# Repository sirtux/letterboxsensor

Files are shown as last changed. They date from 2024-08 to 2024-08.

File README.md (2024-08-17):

# LoRaWAN EU868Mhz Letterbox Sensor

sensing letters in your letterbox via two infrared proximity sensors (HSDL9100),
sending out status via lora / lorawan, using RAK3172 (based on STM32WLE5CC) CPU/RF, powered by a CR2032 battery.

This project is a remake of https://github.com/hierle/letterbox-sensor-v2/, many thanks to the original author!

This design is built in a way, that it can be assembled by a factory house like JLCPCB and you do not need
to fiddle around with soldering small components - especially the HSDL9100 are very fiddly.

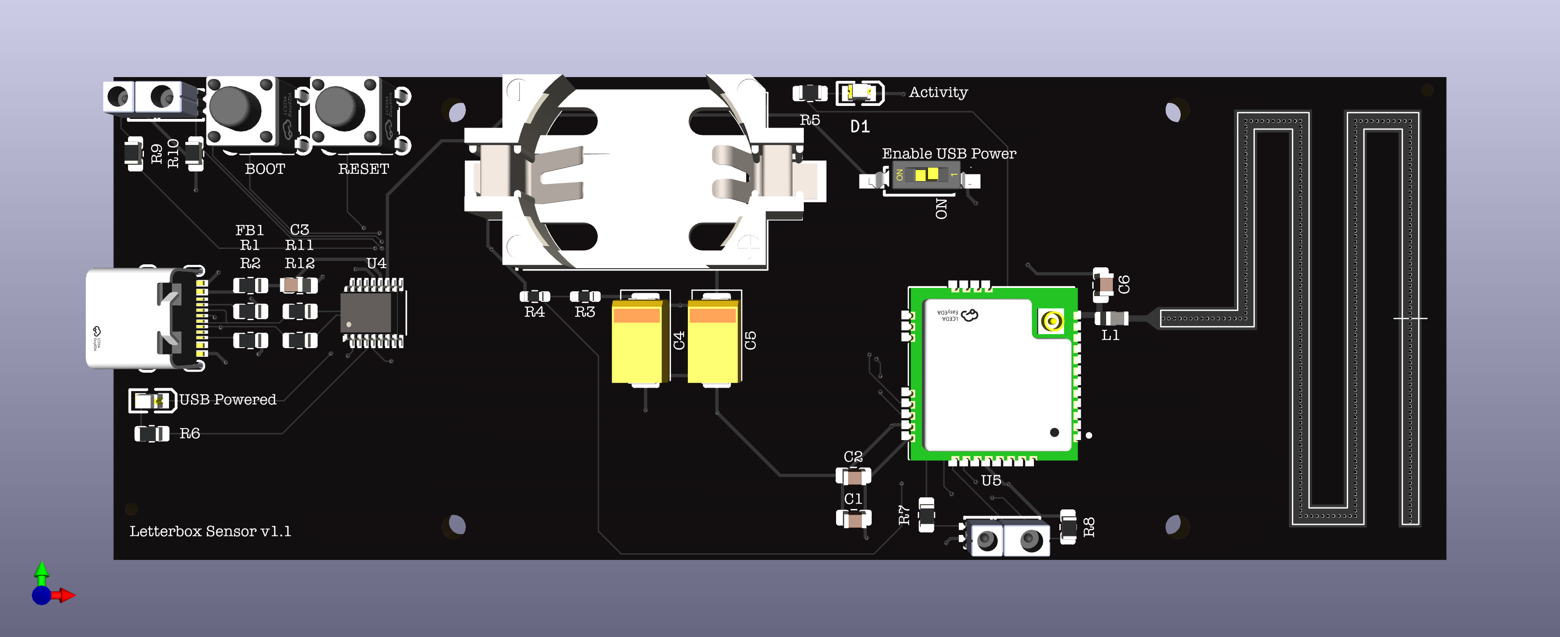
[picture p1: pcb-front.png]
LoRaWAN Letterbox Sensor PCB


Contents:

- ./letterboxsensor/		kicad design files
- ./jlclib/			library files for non standard components
- ./ttn/			Tools to setup TheThingsNetwork
- ./arduino/			Source Code for the sensor
- ./gerber/			Required files for PCB manufacturing
- ./jlcassembly/		Files for JLC Assembly Service

Features:
- using RAKWireless RAK3172 based on STM32WLE5CC
- deep sleep at (measured) 5uA including battery voltage divider and tantalium caps
- two proximity sensors HSDL9100
- USB-C interface for flashing and serial monitor, via FT230XS-R USB-UART
- onboard 868MHz PCB antenna after TI document http://www.ti.com/lit/an/swra227e/swra227e.pdf
- lorawan activation either ABP or OTAA
- battery voltage measurment thru voltage divider (2x 10MOhm)

RAK3172 documentation:

https://docs.rakwireless.com/Product-Categories/WisDuo/RAK3172-Module/Overview/

How to compile:

Follow the instructions on<br>
https://docs.rakwireless.com/Product-Categories/WisDuo/RAK3172-Module/Quickstart/<br>
in short:<br>
- install ArduinoIDE from arduino.cc
- add the following URL to the boards manager URLs section in preferences:
https://raw.githubusercontent.com/RAKWireless/RAKwireless-Arduino-BSP-Index/main/package_rakwireless.com_rui_index.json
- install the "RAKwireless RUI STM32 Boards" from the Boards Manager
- select "WisDuo RAK3172 Evaluation Board" board
- on Mac you might need to install pyserial: sudo pip3 install pyserial
- on Linux you might need to install python3-pyserial
- connect the board, make sure it's powered on (DIP switch)
- select the corresponding serial port
- open the sketch folder
- adjust config.h and lorawan.h
- compile and flash

For configuration adjust config.h and lorawan.h

config.h:
- PERIOD: the time intervall you want the sensor to send it's data, in minutes, default is 30 minutes
- THRESHOLD: the threshold for the sensor readings (empty/full), can later be "overwritten" in e.g. HTML integration
- USE_OTAA: if true, OTAA will be used instead of ABP, so we do not have to worry about frame counters after reset / battery change
- DATARATE and TXPOWER: adjust to your needs, your packets should be reliably received, w/o wasting to much power
- see also the comments for each entry in config.h

lorawan.h:
- set your lorawan keys for either ABP or OTAA
- OTAA_APPEUI or JOINEUI is only needed to select a specific JOIN server, in private networks can be set to any value

Additional notes:
- you will need a *DATA* USB-C cable, a charging only cable will not work, as it's missing the data pins ;-)
- the DIP switch allows to power the device directly from USB, but when using the battery in production environment (letterbox), it should be switched off, not to waist power on the FT230 USB-UART chip

Letterbox sensor v2 lorawan payload package byte structure:

|byte| 0 |  1 2 | 3 4 | 5 6 | 7 |
|----|---|---|---|---|---|
| |0x00=empty|battery |sensor1|sensor2|threshold|
| |0xFF=full |voltage |raw |raw | |

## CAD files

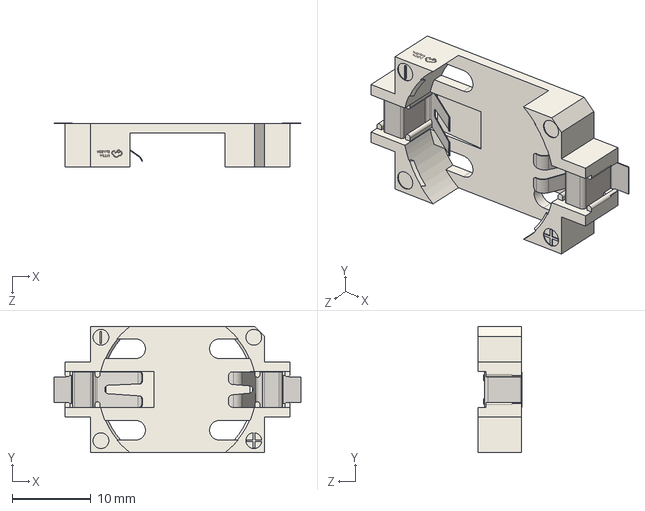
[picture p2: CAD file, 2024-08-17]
jlclib/footprints/models/BAT-TH_CR2032-BS-6-1.step
31.3 x 16.0 x 5.60 mm

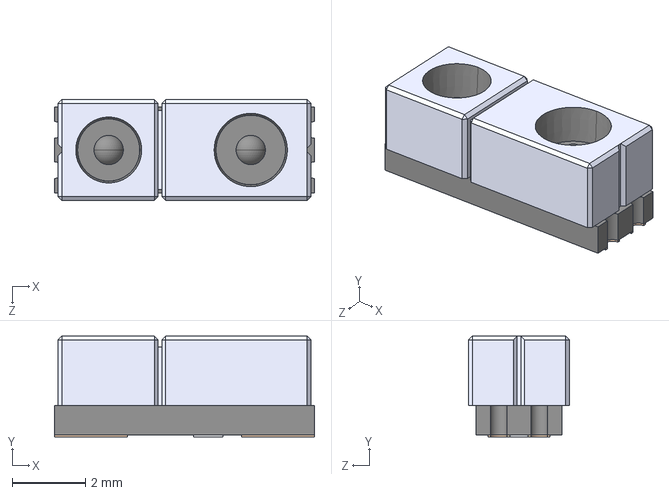
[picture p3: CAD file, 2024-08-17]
jlclib/footprints/models/hsdl9100.step
7.10 x 2.75 x 2.75 mm

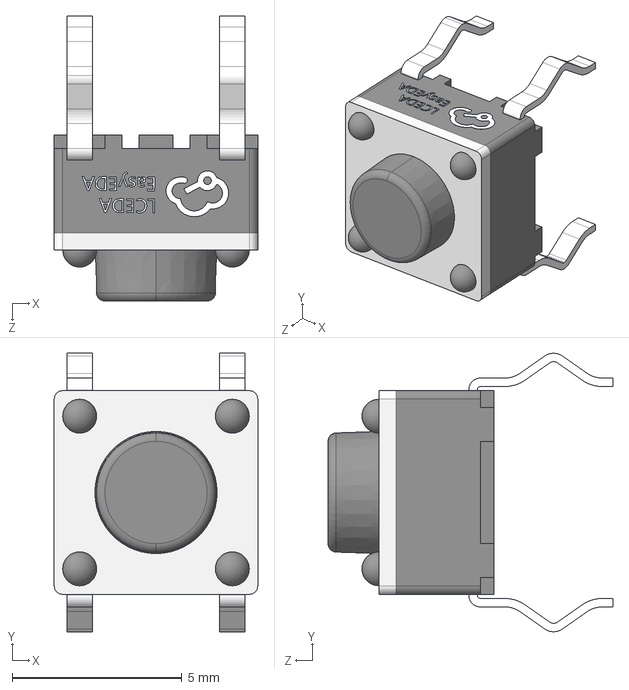
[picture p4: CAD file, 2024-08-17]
jlclib/footprints/models/SW-TH_4P-L6.0-W6.0-P4.50-LS6.5.step
6.00 x 8.21 x 8.40 mm

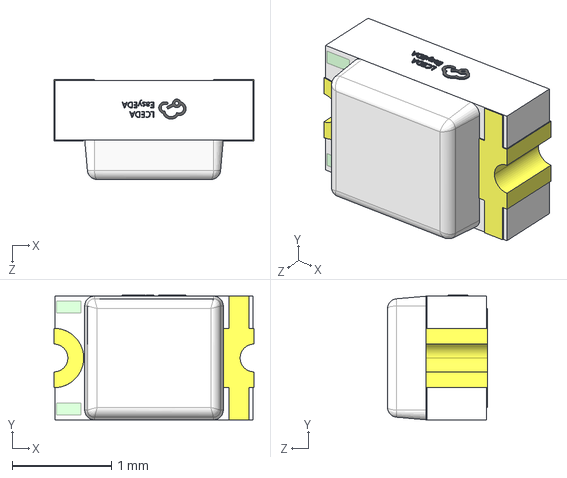
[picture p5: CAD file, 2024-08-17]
jlclib/footprints/models/LED0805-R-RD.step
2.02 x 1.26 x 1.01 mm

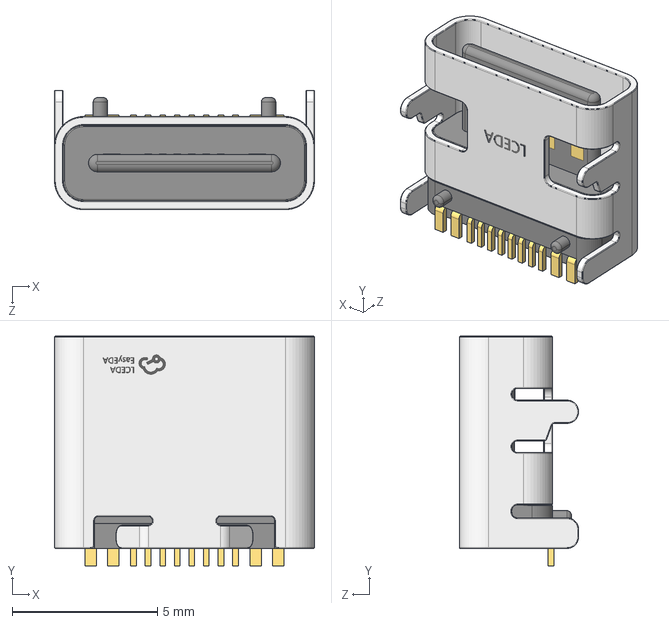
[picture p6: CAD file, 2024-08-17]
jlclib/footprints/models/USB-C-SMD_TYPE-C-USB-17.step
8.94 x 7.90 x 4.10 mm

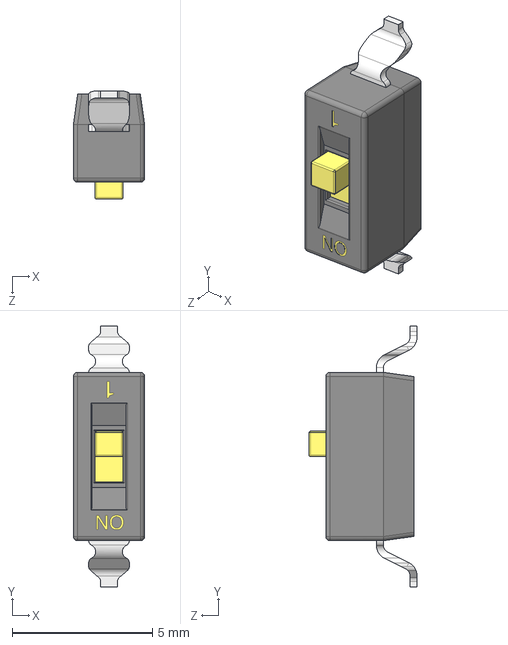
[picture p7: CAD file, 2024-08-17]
jlclib/footprints/models/SW-SMD_DSIC01LSGET.step
2.54 x 9.30 x 3.85 mm

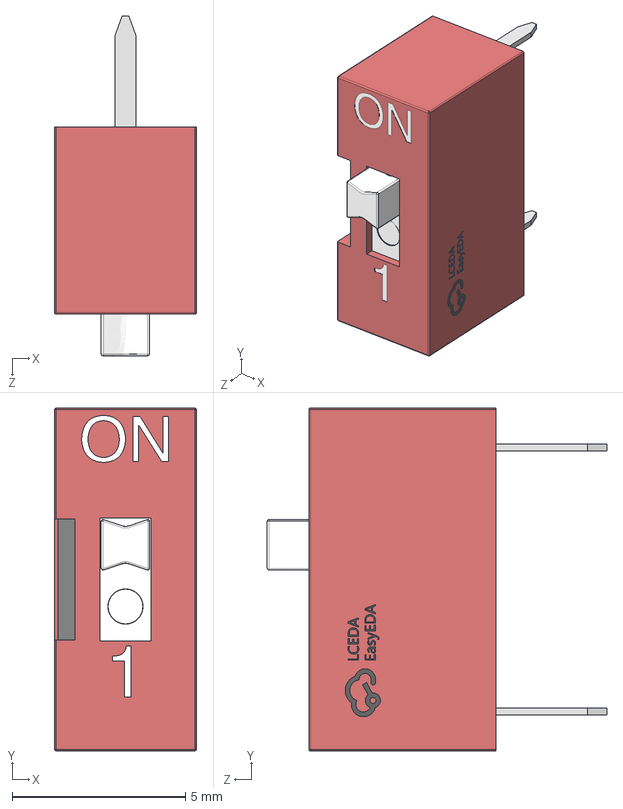
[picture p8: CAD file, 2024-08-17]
jlclib/footprints/models/SW-TH_DSWB01LHGET.step
4.10 x 9.90 x 9.80 mm

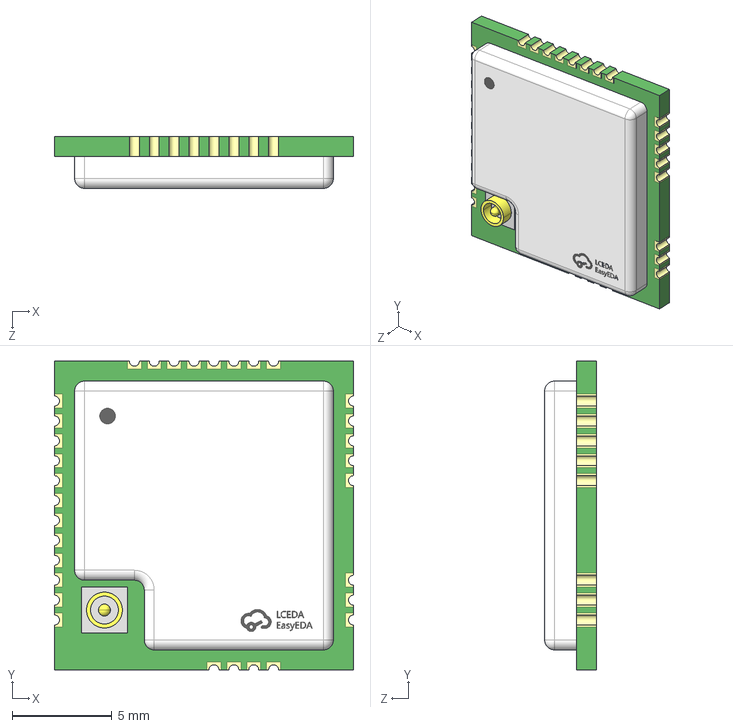
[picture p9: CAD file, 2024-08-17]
jlclib/footprints/models/WIRELM-SMD_32P-L15.5-W15.0-P1.00.step
15.0 x 15.5 x 2.62 mm

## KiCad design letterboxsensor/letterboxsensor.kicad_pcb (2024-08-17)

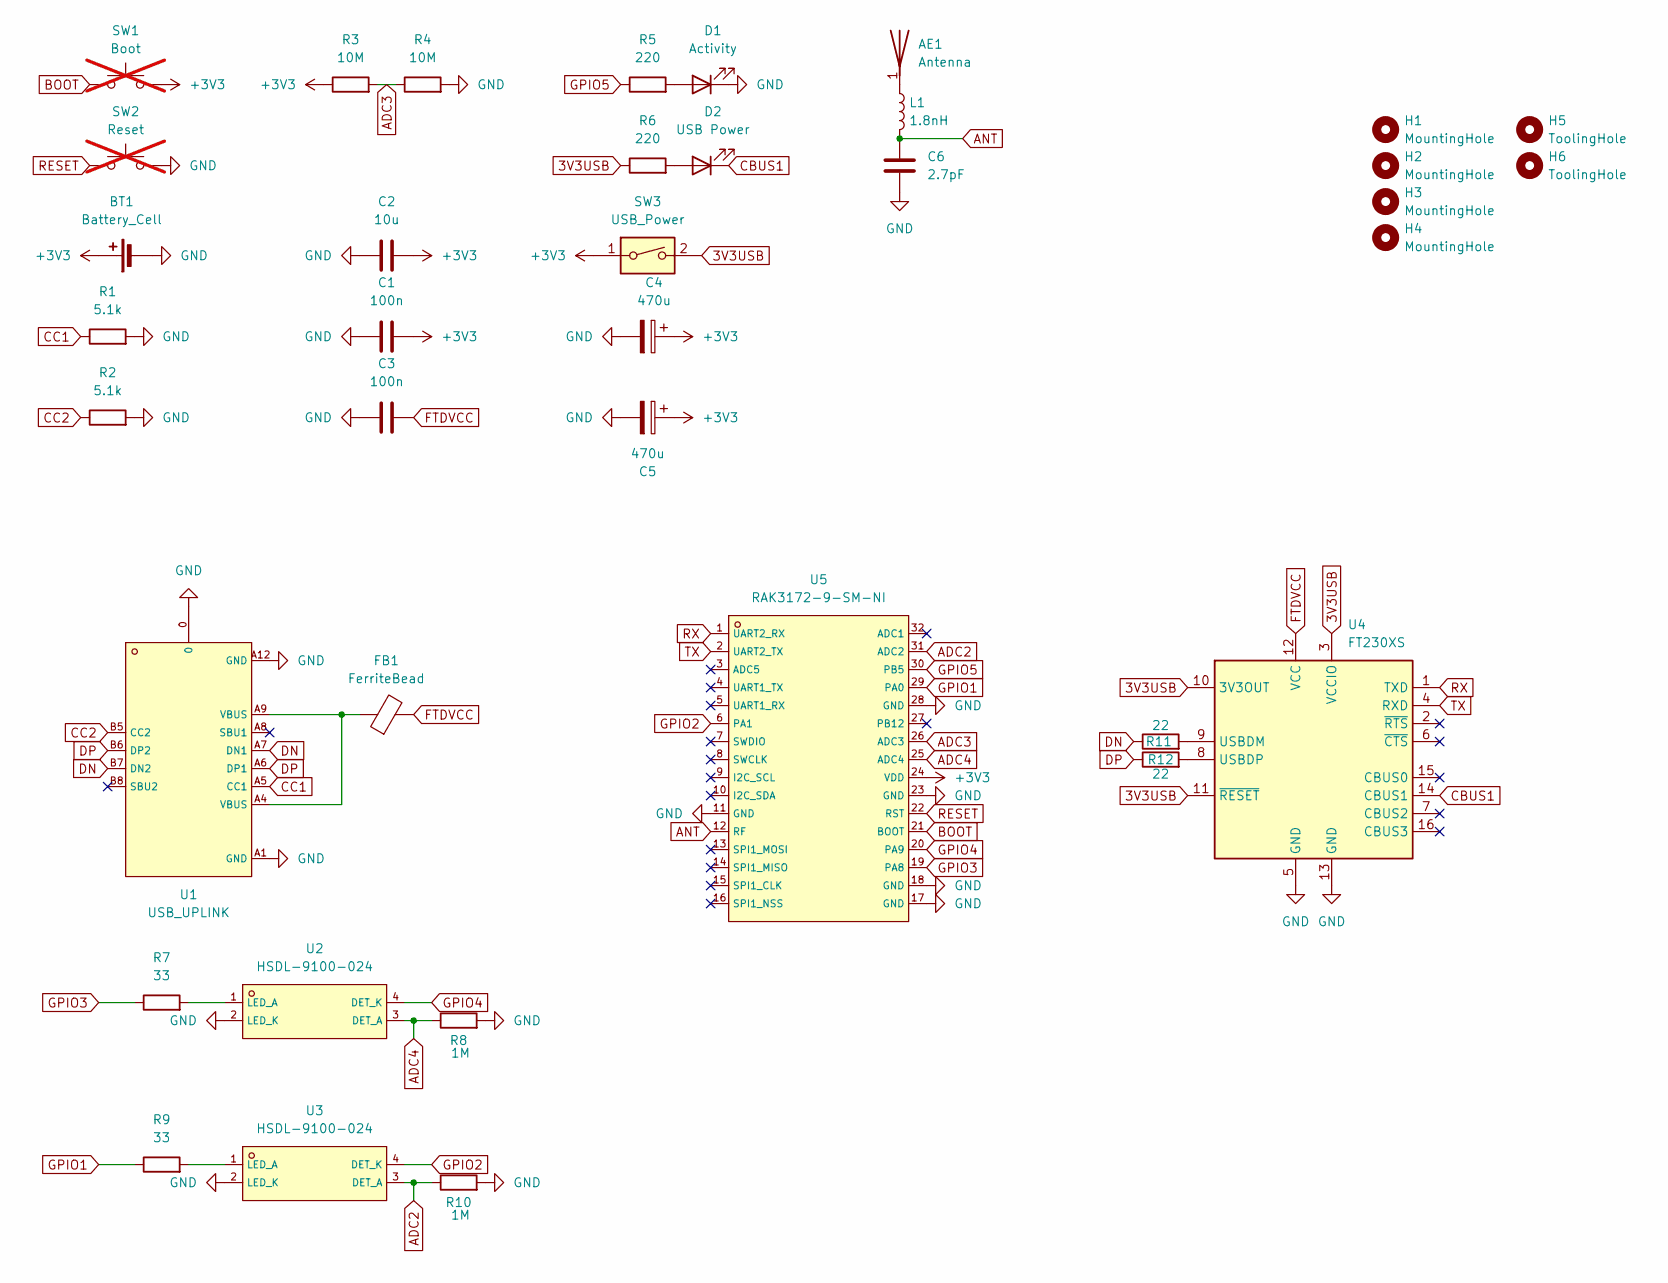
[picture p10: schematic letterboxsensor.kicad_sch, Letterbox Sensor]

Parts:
AE1: Antenna; TI-DN024-SL
BT1: Battery_Cell; BAT-TH_CR2032-BS-6-1; LCSC C70377
C1, C3: 100n; C_0805_2012Metric_Pad1.18x1.45mm_HandSolder; LCSC C49678
C2: 10u; C_0805_2012Metric_Pad1.18x1.45mm_HandSolder; LCSC C440198
C4, C5: 470u; CP_EIA-7343-43_Kemet-X_Pad2.25x2.55mm_HandSolder; LCSC C7234
C6: 2.7pF; C_0805_2012Metric_Pad1.18x1.45mm_HandSolder; LCSC C1803
D1: Activity; LED0805-R-RD; LCSC C2297
D2: USB Power; LED0805-R-RD; LCSC C2297
FB1: FerriteBead; R_0805_2012Metric_Pad1.20x1.40mm_HandSolder; LCSC C1017
H1, H2, H3, H4: MountingHole; MountingHole_2.2mm_M2_ISO7380
H5, H6: ToolingHole; ToolingHole_JLCSMT
L1: 1.8nH; L_0805_2012Metric; LCSC C578016
R1, R2: 5.1k; R_0805_2012Metric_Pad1.20x1.40mm_HandSolder; LCSC C27834
R3, R4: 10M; R_0603_1608Metric_Pad0.98x0.95mm_HandSolder; LCSC C7250
R5, R6: 220; R_0805_2012Metric_Pad1.20x1.40mm_HandSolder; LCSC C17557
R7, R9: 33; R_0805_2012Metric_Pad1.20x1.40mm_HandSolder; LCSC C17634
R8, R10: 1M; R_0805_2012Metric_Pad1.20x1.40mm_HandSolder; LCSC C17514
R11, R12: 22; R_0805_2012Metric_Pad1.20x1.40mm_HandSolder; LCSC C17561
SW1: Boot; SW-TH_4P-L6.0-W6.0-P4.50-LS6.5; LCSC C13828; not fitted
SW2: Reset; SW-TH_4P-L6.0-W6.0-P4.50-LS6.5; LCSC C13828; not fitted
SW3: USB_Power; SW-SMD_DSIC01LSGET; LCSC C54948
U1: USB_UPLINK; USB-C-SMD_TYPE-C-USB-17; LCSC C167321
U2, U3: HSDL-9100-024; OPTO-SMD_HSDL-9100-024; LCSC C5186960
U4: FT230XS; SSOP-16_3.9x4.9mm_P0.635mm; LCSC C69082
U5: RAK3172-9-SM-NI; WIRELM-SMD_32P-L15.5-W15.0-P1.00; LCSC C18548052

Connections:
3V3USB: R6.1, SW3.2, U4.3 (VCCIO), U4.10 (3V3OUT), U4.11 (~RESET)
+3V3: BT1.1 (+), C1.2, C2.2, C4.1, C5.1, R3.1, SW1.2, SW3.1, U5.24 (VDD)
ADC2: R10.1, U3.3 (DET_A), U5.31 (ADC2)
ADC3: R3.2, R4.1, U5.26 (ADC3)
ADC4: R8.1, U2.3 (DET_A), U5.25 (ADC4)
ANT: C6.1, L1.2, U5.12 (RF)
BOOT: SW1.1, U5.21 (BOOT)
CBUS1: D2.1 (K), U4.14 (CBUS1)
CC1: R1.1, U1.A5 (CC1)
CC2: R2.1, U1.B5 (CC2)
DN: R11.1, U1.A7 (DN1), U1.B7 (DN2)
DP: R12.1, U1.A6 (DP1), U1.B6 (DP2)
FTDVCC: C3.2, FB1.2, U4.12 (VCC)
GND: BT1.2 (-), C1.1, C2.1, C3.1, C4.2, C5.2, C6.2, D1.1 (K), R1.2, R2.2, R4.2, R8.2, R10.2, SW2.2, U1.0, U1.A1 (GND), U1.A12 (GND), U2.2 (LED_K), U3.2 (LED_K), U4.5 (GND), U4.13 (GND), U5.11 (GND), U5.17 (GND), U5.18 (GND), U5.23 (GND), U5.28 (GND)
GPIO1: R9.1, U5.29 (PA0)
GPIO2: U3.4 (DET_K), U5.6 (PA1)
GPIO3: R7.1, U5.19 (PA8)
GPIO4: U2.4 (DET_K), U5.20 (PA9)
GPIO5: R5.1, U5.30 (PB5)
unnamed: AE1.1 (A), L1.1
unnamed: D1.2 (A), R5.2
unnamed: D2.2 (A), R6.2
unnamed: FB1.1, U1.A4 (VBUS), U1.A9 (VBUS)
unnamed: R7.2, U2.1 (LED_A)
unnamed: R9.2, U3.1 (LED_A)
unnamed: R11.2, U4.9 (USBDM)
unnamed: R12.2, U4.8 (USBDP)
RESET: SW2.1, U5.22 (RST)
RX: U4.1 (TXD), U5.1 (UART2_RX)
TX: U4.4 (RXD), U5.2 (UART2_TX)

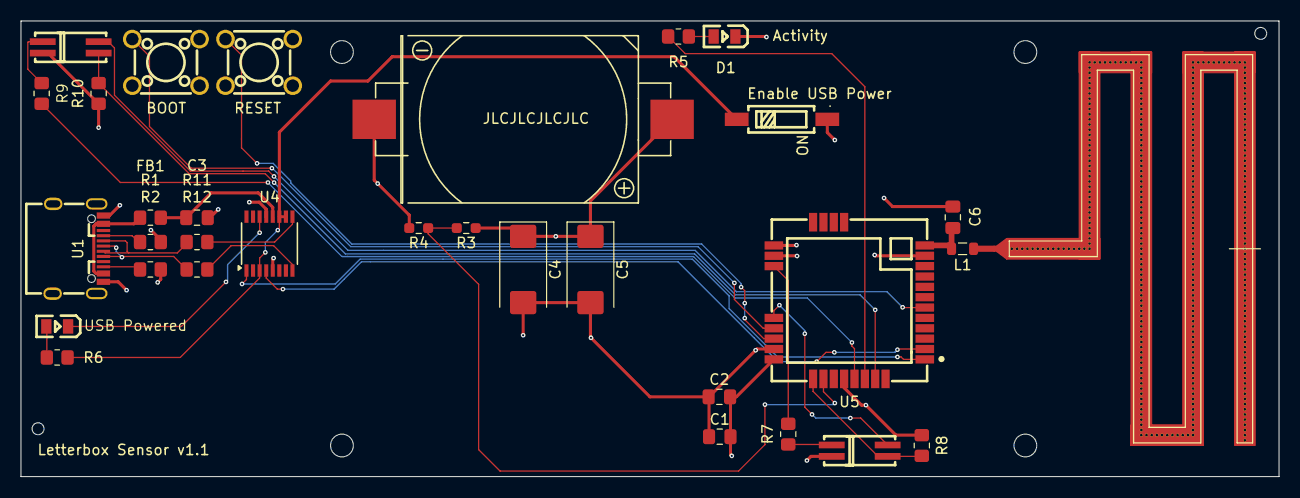
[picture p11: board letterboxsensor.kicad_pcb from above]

Board: 4 copper layers, 121.5 x 44.0 mm, 38 parts (0 on the bottom side), 30 nets.

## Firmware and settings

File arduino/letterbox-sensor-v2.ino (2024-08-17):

// 
// letterbox-sensor-v2.ino
//

#include <Arduino.h>
#include "config.h"
#include "pins.h"
#include "lorawan.h"

void setup() {

  // set up serial line
  Serial.begin(115200);
  delay(1000);
  Serial.println("-------------------------");
  Serial.println("Letterbox sensor v2");
  Serial.printf("Firmware Version: %s\r\n", api.system.firmwareVersion.get().c_str());
  Serial.printf("CLI Version: %s\r\n", api.system.cliVersion.get().c_str());
  Serial.printf("API Version: %s\r\n", api.system.apiVersion.get().c_str());
  Serial.printf("Model ID: %s\r\n", api.system.modelId.get().c_str());
  Serial.printf("Hardware ID: %s\r\n", api.system.chipId.get().c_str());
  Serial.println("-------------------------");

  // set pinmodes
  pinMode(statusled, OUTPUT);
  pinMode(irled1, OUTPUT);
  pinMode(irled2, OUTPUT);
  pinMode(irdiode1, OUTPUT);
  pinMode(irdiode2, OUTPUT);
  pinMode(irsens1, INPUT);
  pinMode(irsens2, INPUT);

  // init lorawan
  lorawan_init();

  // set low power mode
  if (!api.system.lpm.set(1)) {	Serial.println("Set low power mode failed! \r\n");}

  // ADC mode
  //udrv_adc_set_mode(UDRV_ADC_MODE_3_3);

  // blink led once on startup
  digitalWrite(statusled,HIGH);
  delay(1000);
  digitalWrite(statusled,LOW);

	// create timer
	api.system.timer.create(RAK_TIMER_0, sensor_handler, RAK_TIMER_PERIODIC);
  // start timer
	api.system.timer.start(RAK_TIMER_0, PERIOD*60*1000, NULL);

  // get and send sensor values on boot
	sensor_handler(NULL);
}

// read sensor values and send lorawan package
void sensor_handler(void *) {

  // variables
  unsigned int s1 = 0; // sensor#1
  unsigned int s2 = 0; // sensor#2
  unsigned int bat = 0; // battery

  // data buffer
  uint8_t data_length = 8;
  uint8_t data[data_length];

  // measure sensor #1
  digitalWrite(irled1,HIGH);
  digitalWrite(irdiode1,HIGH);
  delay(10);
  for(int i = 0 ; i <3 ; i++){
    delay(25);
    s1 += analogRead(irsens1);
  }
  s1=s1/3;
  digitalWrite(irled1,LOW);
  digitalWrite(irdiode1,LOW);
  Serial.printf("Sensor#1: %d\r\n", s1);

  // measure sensor #2
  digitalWrite(irled2,HIGH);
  digitalWrite(irdiode2,HIGH);
  delay(10);
  for(int i = 0 ; i <3 ; i++){
    delay(25);
    s2 += analogRead(irsens2);
  }
  s2=s2/3;
  digitalWrite(irled2,LOW);
  digitalWrite(irdiode2,LOW);
  Serial.printf("Sensor#2: %d\r\n", s2);

  // letterbox full/empty
  if((s1 > THRESHOLD)||(s2 > THRESHOLD)) { data[0] = 0xFF; }
  else { data[0] = 0x00; }

  // battery voltage from external voltage divider
  analogReadResolution(12);
  delay(25);
  bat=analogRead(vdiv);
  Serial.printf("Voltage: %d\r\n", bat);
  analogReadResolution(10);

  // battery
  data[1] = (bat & 0xFF);
  data[2] = ((bat >> 8) & 0xFF);

  // sensor#1
  data[3] = (s1 & 0xFF);
  data[4] = ((s1 >> 8) & 0xFF);

  // sensor#2
  data[5] = (s2 & 0xFF);
  data[6] = ((s2 >> 8) & 0xFF);

  // threshold
  data[7] = THRESHOLD;

  // temperature N/A for now
  //data[8] = readTemp();

  Serial.println("-------------------------");

  // send data via lorawan
  lorawan_send(data, data_length);
  // blink led when sending data
  digitalWrite(statusled,HIGH);
  delay(1000);
  digitalWrite(statusled,LOW);

}


void loop(){
  // destroy this busy loop and use a timer instead,
  // so that the system thread can auto enter low power mode by api.system.lpm.set(1)
  api.system.scheduler.task.destroy();
}

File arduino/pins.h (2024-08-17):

//
// pins.h
//

// pin mappings

// status led
#define statusled PB5

// sensor #1
// ir-led of proximity sensor#1 (invisible)
#define irled1 PA0
// power in for diode in proximity sensor
#define irdiode1 PA1
// adc pin (connect to output of sensor)
#define irsens1 PB4

// sensor #2
// ir-led of proximity sensor#1 (invisible)
#define irled2 PA8
// power in for diode in proximity sensor
#define irdiode2 PA9
// adc pin (connect to output of sensor)
#define irsens2 PA10

// adc pin battery voltage divider
#define vdiv PB2

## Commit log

2024-08-17 Added KiCad .gitignore
2024-08-17 Release v1.1
    [BAT-TH_CR2032-BS-6-1.step, LED0805-R-RD.step, SW-SMD_DSIC01LSGET.step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]
2024-08-17 Updated the PCB rendering
